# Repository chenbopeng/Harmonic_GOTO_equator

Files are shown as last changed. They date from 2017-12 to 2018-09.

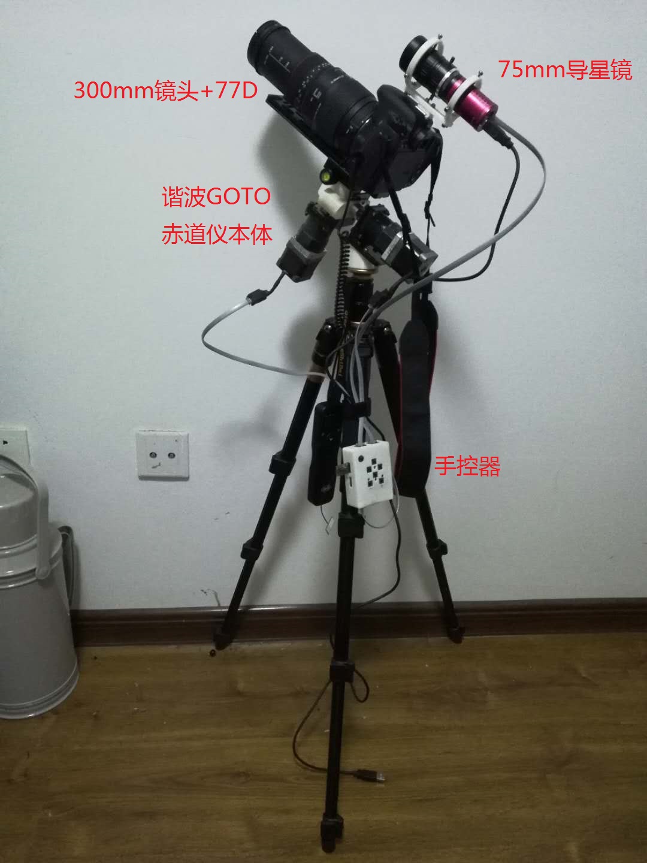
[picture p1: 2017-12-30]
doc/设备总体图.jpg

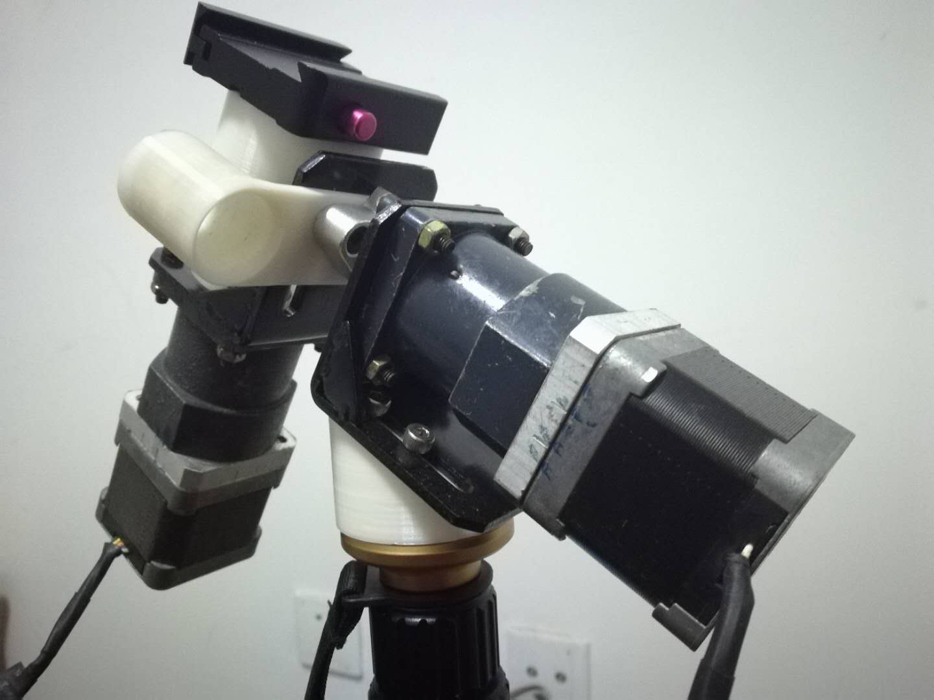
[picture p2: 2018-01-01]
doc/赤道仪本体实物图.jpg

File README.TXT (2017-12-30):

谐波GOTO赤道仪说明
重要声明：
本设计提供了一种谐波GOTO赤道仪的制作方法及全部原始技术资料。
本设计从共享之日起可供任何组织和个人免费获取，但禁止任何组织和个人在未经允许的条件下用于商业用途。
制作者需自行为其制作的实体所造成的一切后果负责，本设计作者不承担任何责任。
作者邮箱：c290129114@163.com

文件说明：
SRC文件夹为手控器源码及固件文件，开发及调试环境为Keil uVision5。
MACH文件夹为机械结构设计图文件，包括3D打印所需的STL文件等，设计软件为SOLIDWORKS 2015。
PCB文件夹为原理图与PCB设计图文件，设计软件为Altium Designer16。
DOC文件夹为文本及图片说明文件，包括安装及使用说明、装配示意图等。

如果您想快速制作一台属于自己的便携谐波GOTO赤道仪，可按照DOC文件夹下的说明文件按步骤制作即可！

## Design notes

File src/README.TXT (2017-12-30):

谐波GOTO控制手柄固件说明
硬件：
100减速比谐波电机（可通过修改EQ3D.H中的定义适配别的电机）
STM32C8T6最小系统
TMC2100步进电机驱动器（固定16细分，内差分至256细分）

版本实现：
双轴电跟,赤经轴跟踪精度无理论误差
按键控制及导星,速度2X,10X,100X,800X按键切换
南北半球、东西朝向按键切换
Stellarium及SkySafari5有线或WIFI无线GOTO控制

使用方法：
1.将赤道仪架设好并对准极轴，按键选择正确的半球和朝向
2.控制赤道仪使相机正对天空中（天赤道附近有助于提高精度）的任一亮星
3.stellarium或SkySafari5连接手柄，软件中找到该亮星并点击GOTO至此星
4.此时软件中望远镜的标记点会从南天极移动至该星，而赤道仪并不会动
5.此时已完成系统的初始化，可以开始GOTO至任意天体（注意!!!防止相机及镜头打腿!!!）

需改进：
中天翻转算法
回差控制

通信过程：
建立连接时
Stellarium发送 “#:GR#”     下位机回复 “00:00:01#”       //下位机回复当前赤经值
Stellarium发送 “#:GD#”     下位机回复 “+00:00:01#”      //下位机回复当前赤纬值

按CTRL1指向目标时
Stellarium发送“#:Q#:Sr 11:36:05#”    下位机回复“1”      //上位机发送目标赤经值，下位机回复1表示收到
Stellarium发送“:Sd -47?28:13#”       下位机回复“1”      //上位机发送目标赤纬值，下位机回复1表示收到
Stellarium发送“:MS#”                 下位机回复“0”      //上位机询问下位机是否能转到该位置，下位机回复0表示可以

skasafari5建立连接
“:GR#”
“:GD#”

“:Sr00:14:08#”
“:Sd+13*34:40#”
“:MS#”

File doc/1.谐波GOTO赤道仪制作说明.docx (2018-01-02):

# 谐波GOTO赤道仪制作说明

# 重要声明

本设计提供了一种谐波GOTO赤道仪的制作方法及全部原始技术资料。

本设计从共享之日起可供任何组织和个人免费获取，但禁止任何组织和个人在未经允许的条件下用于商业用途。

制作者需自行为其制作的实体所造成的一切后果负责，本设计作者不承担任何责任。

作者邮箱：c290129114@163.com

# 综述

## 制作谐波GOTO赤道仪的初衷

本人菜鸟天爱一枚，因为工作长期在各大城市出差，又经常手痒，EQ3D+小黑无法带在身边，因而萌生攒一套便携深空设备的想法，然而市面上已有的赤道仪系统的价格、便携性、易用性均让我不太满意，所以利用自己的专长，开始自己制作谐波GOTO赤道仪。

我的设计参考了论坛多位大神的设计经验，在此一并向他们表示感谢！

本赤道仪设计思路着重于便携、低成本和系统简洁，并在此基础上达到尽可能高的精度。可以看到几乎每一个零件和模块都是为这个指导思想服务。

## 本赤道仪目前实现功能

本赤道仪目前实现了：

1.双轴电跟（赤经轴跟踪精度无理论误差）

2.按键控制及导星控制

3. 2X,10X,100X,800X速度按键切换

4.南北半球、东西朝向按键切换

5.Stellarium及SkySafari5有线或WIFI无线GOTO控制

## 本赤道仪设计特色

1. 采用100:1减速比的谐波减速器，谐波减速器精度高，无回差。
2. 采用内差分至256细分的TMC2100高端步进电机驱动器，静音、无抖动、精度高。
3. 采用LX200串口通信协议，通过WIFI转串口模块，实现Stellarium及SkySafari5对赤道仪的无线控制，方便使用笔记本或手机在外场控制赤道仪。
4. 赤道仪本体重量1.8kg左右，背包即可轻松出行。

## 赤道仪测试效果展示

1.Stellarium无线控制。

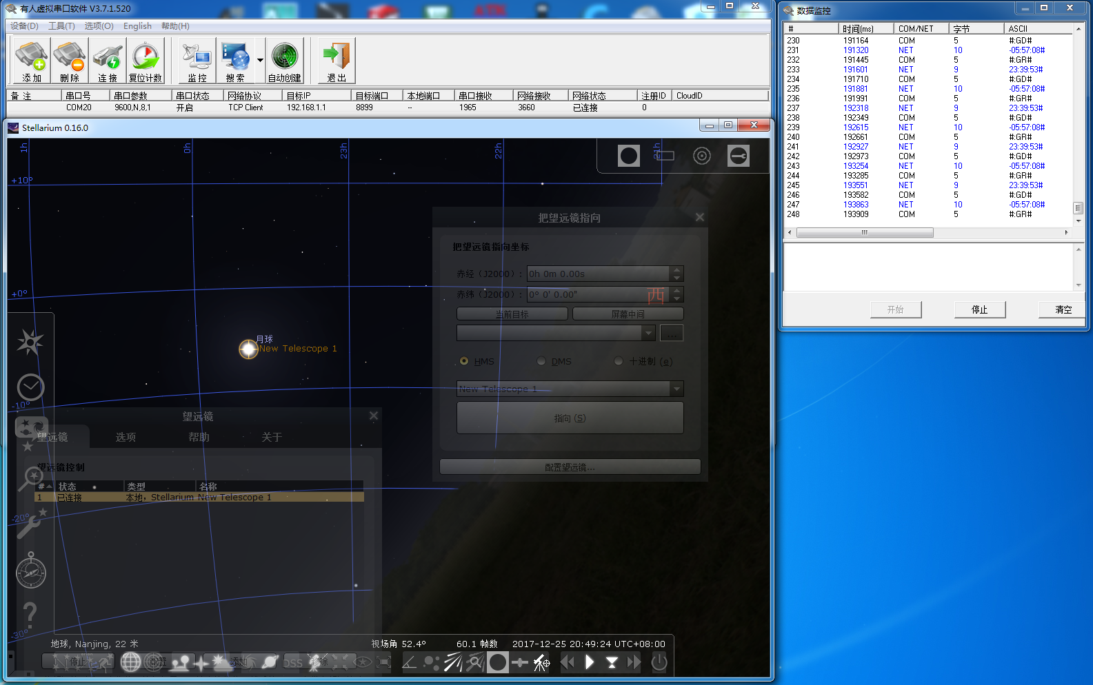
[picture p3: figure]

2. SkySafari5无线控制

3.导星曲线

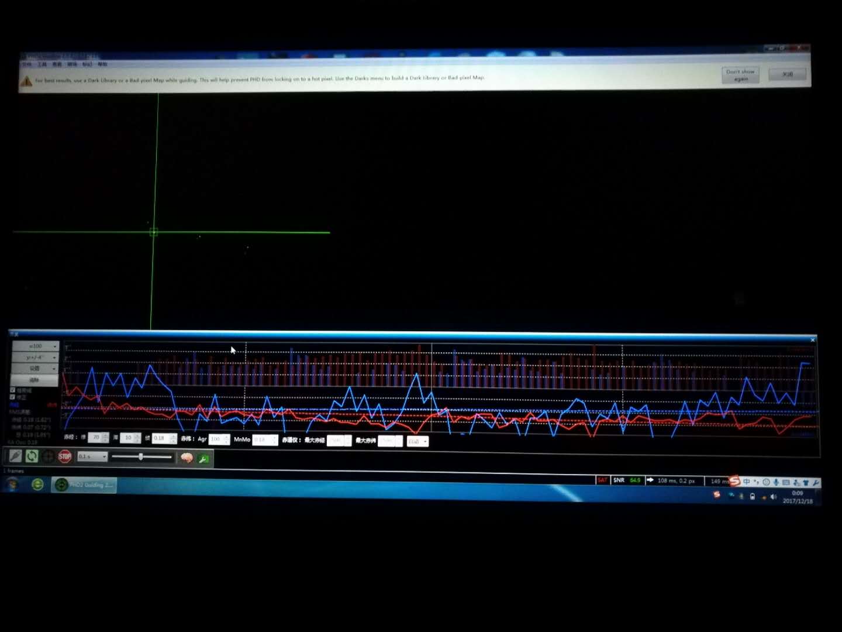
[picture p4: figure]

4.大角GOTO到M45（如图所示300mm镜头goto到位后还是需要微调，误差有可能是步进电机没有加减速控制而造成的丢步或超步导致的，也有可能是三脚架较差，微弱形变或抖动所造成）

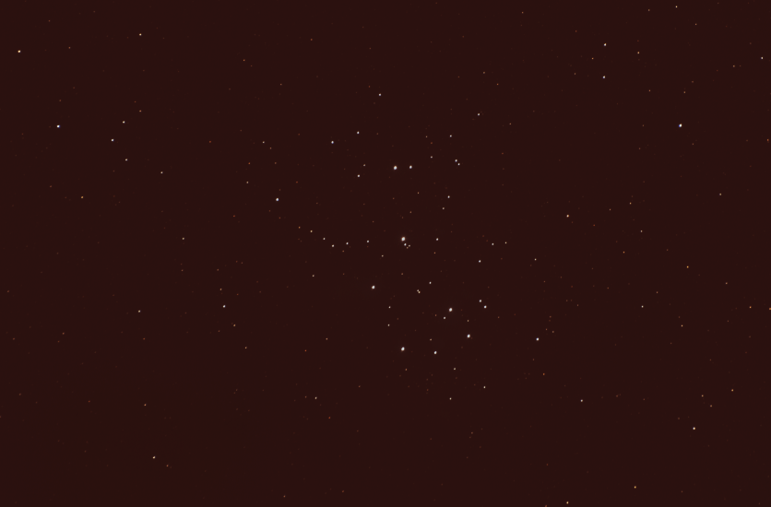
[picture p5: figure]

5.赤道仪整装图

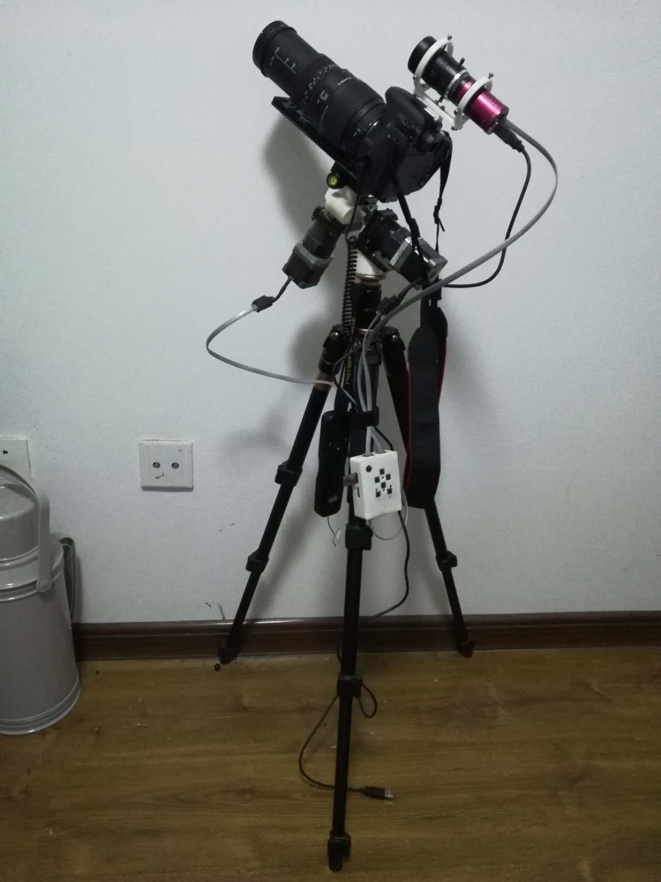
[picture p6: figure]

# 准备材料

接下来开始进入正题，如何制作一台自己的谐波GOTO赤道仪。

## 准备工具

电烙铁等焊接工具

万用表

内六扳手一套（尤其是M4）

十字起

热缩管或电工胶布

尖嘴钳

细导线若干

## 准备材料

详见《2.谐波GOTO赤道仪bom清单.xlsx》

## 调整电压

稳压模块在安装之前需要调整电压，以防电压过高烧毁后续电路。调压时，如下图左端供电（注意电源极性），右端用万用表电压档监测输出电压值，用小十字起旋转可调电位器，控制输出电压为5-5.5V左右即可。

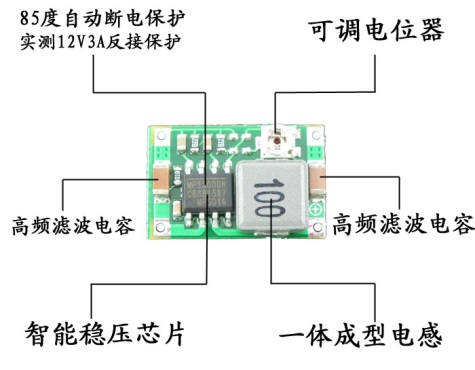
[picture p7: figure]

# 赤道仪本体制作

将材料如图安装即可。

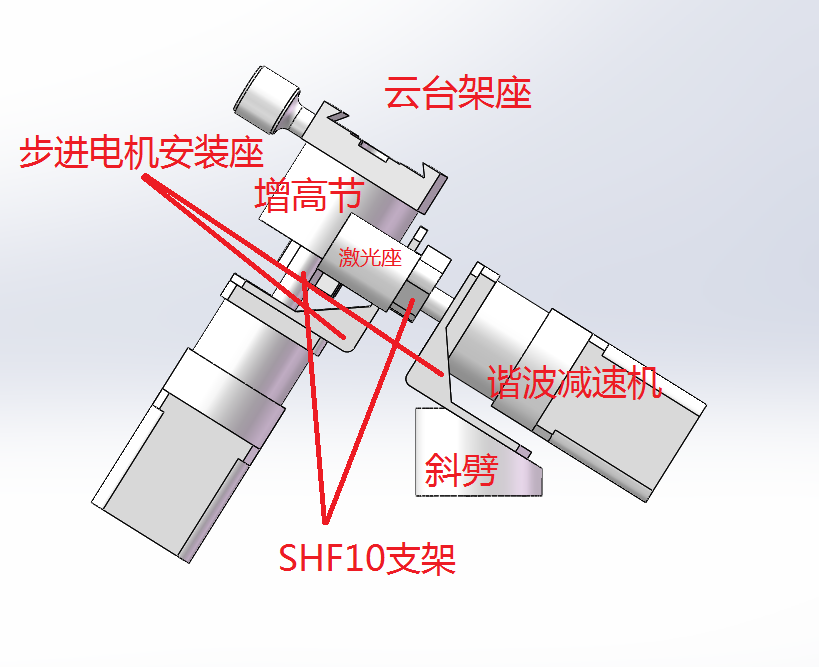
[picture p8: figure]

实物图


# 赤道仪手柄制作

## 手柄外观图

手柄由四部分组成，分别是主控板、按键板、wifi模块和外壳。

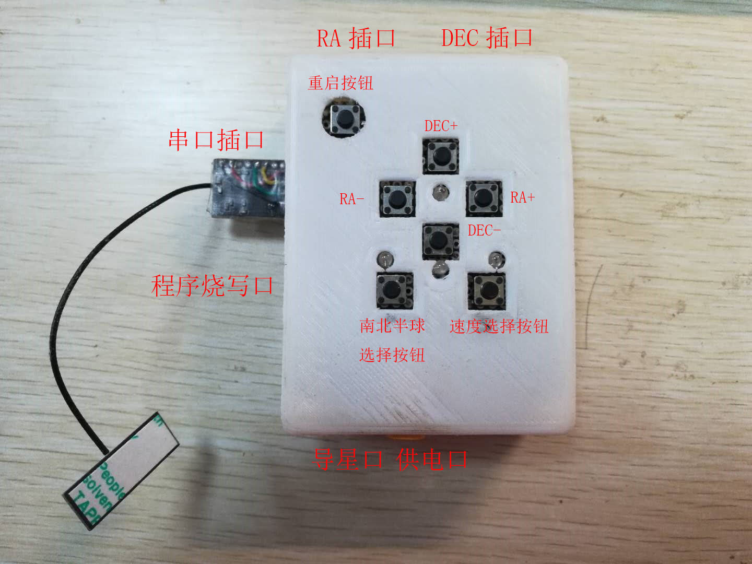
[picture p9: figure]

## 制作主控板

主控板布局如图

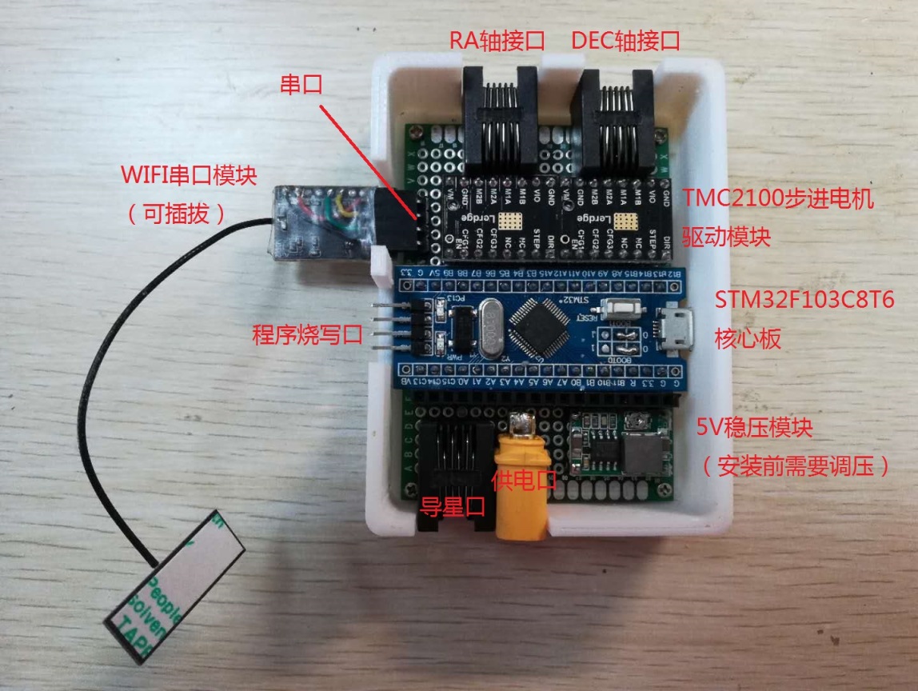
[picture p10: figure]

主控板背面焊线如图所示

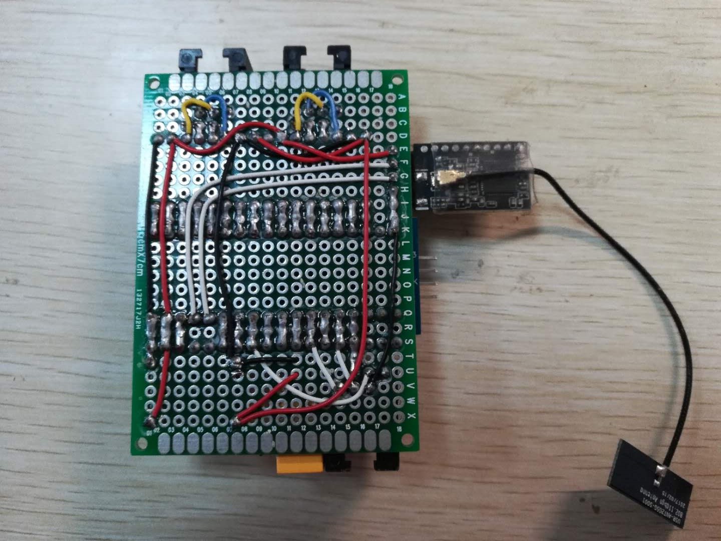
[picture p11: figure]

看不清焊线图也可以根据原理图进行焊线。

主控板原理图如下：

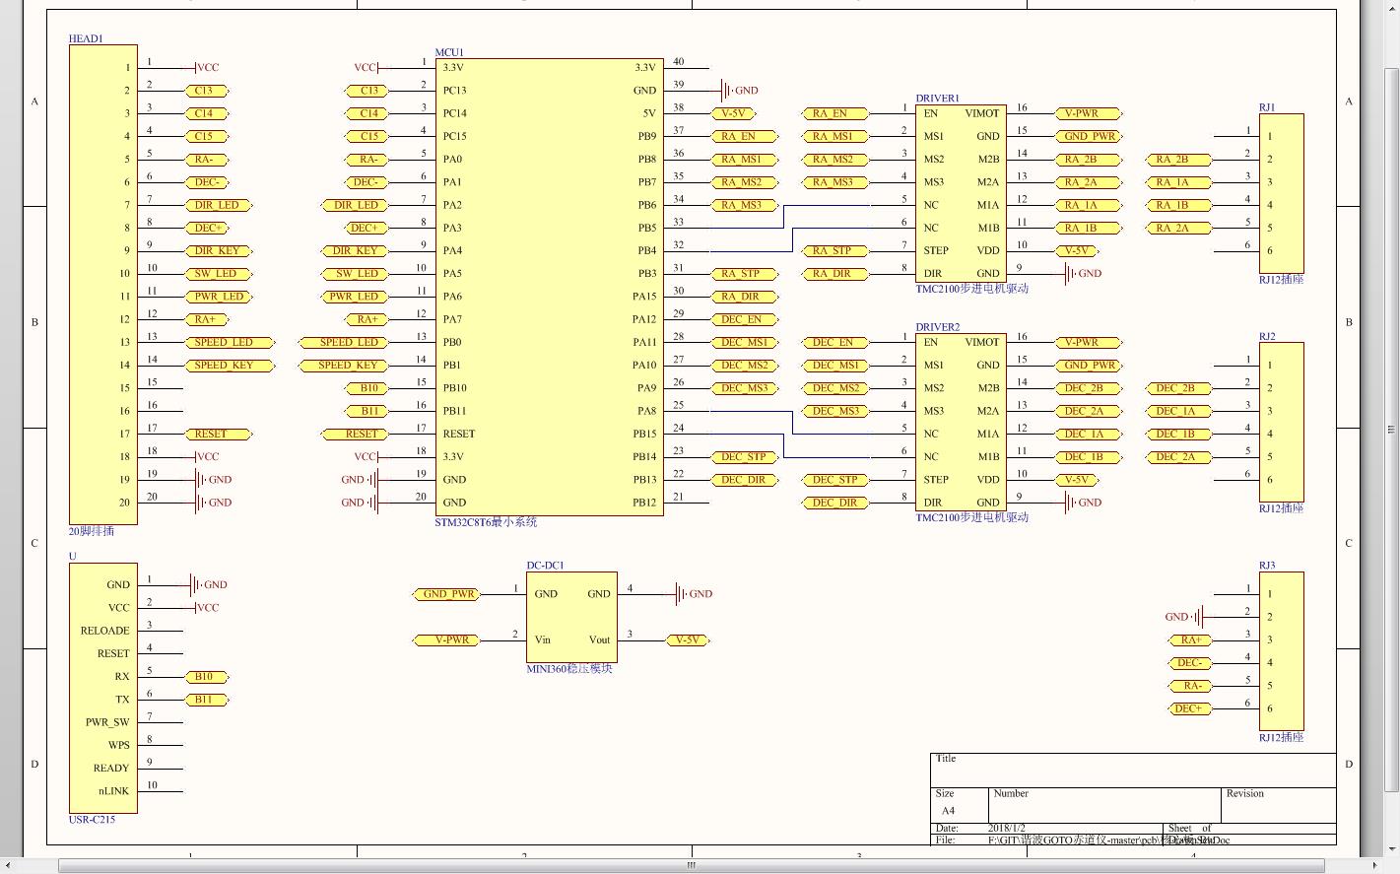
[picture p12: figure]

## 调整驱动器电流

主控板制作完成之后，首先需要对步进电机驱动器，即TMC2100模块进行电流调整之后才能连接步进电机，否则可能出现电机供电不足或者供电太大烧毁电机！

电流调整非常简单，先对主控板供电，然后在TMC2100驱动器上找到与下图红色表笔对应的小孔，该小孔内有一个可以用小一字起旋转的电位器，通过旋转该电位器并如图测量该点的电压，调整该点电压为0.26V即263mv即可（I=Vref*1.9，此时I=0.5A，这是经多次测试得到的较好的工作电流值）

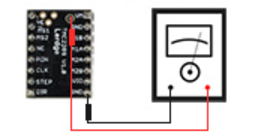
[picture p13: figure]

## 制作按键板

按键板正面布局（注意按钮的摆放方向）

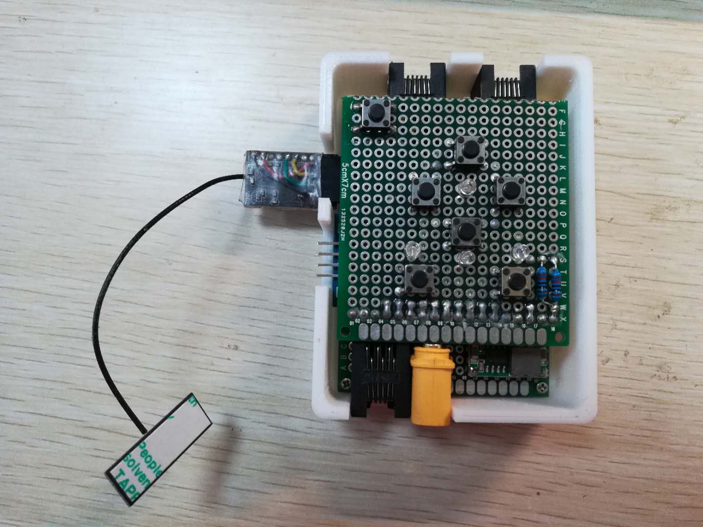
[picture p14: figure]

按键板背面焊接图

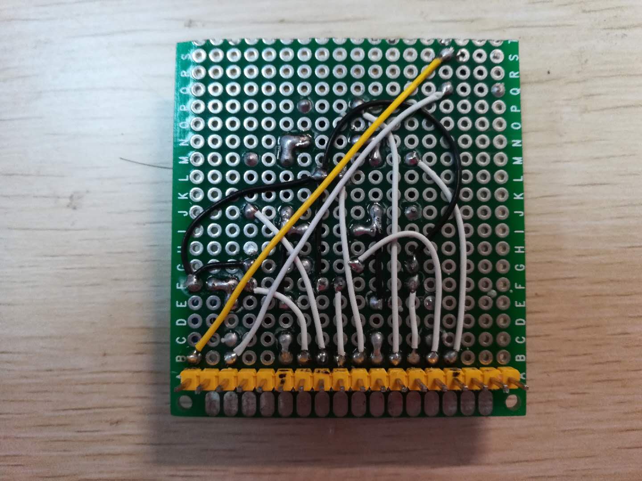
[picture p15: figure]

## 烧写固件

1. 安装j-link驱动，连接烧写器和电脑及赤道仪手柄。
2. 打开SEGGER>J-Link V4.90>J-flash软件。
3. 点击create a new project>star j-flash。
4. 点击options>project settings，如图进行设置。

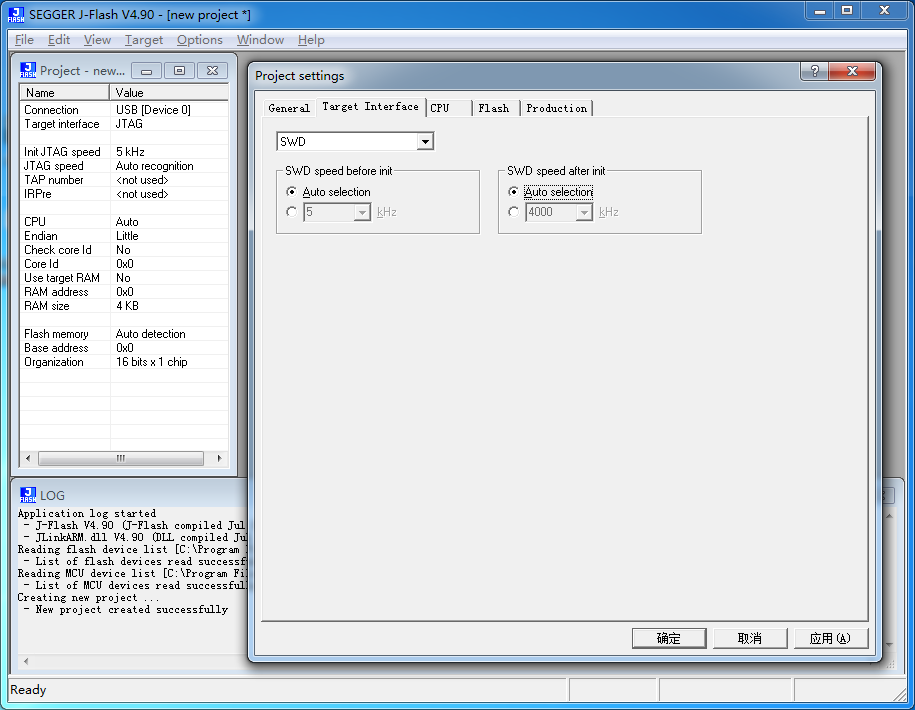
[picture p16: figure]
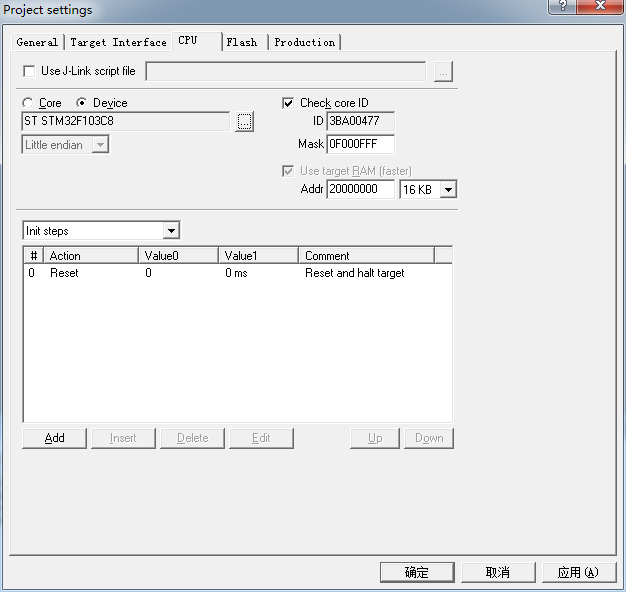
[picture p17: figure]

5. 点击file>open data file，如图选择.HEX固件文件。

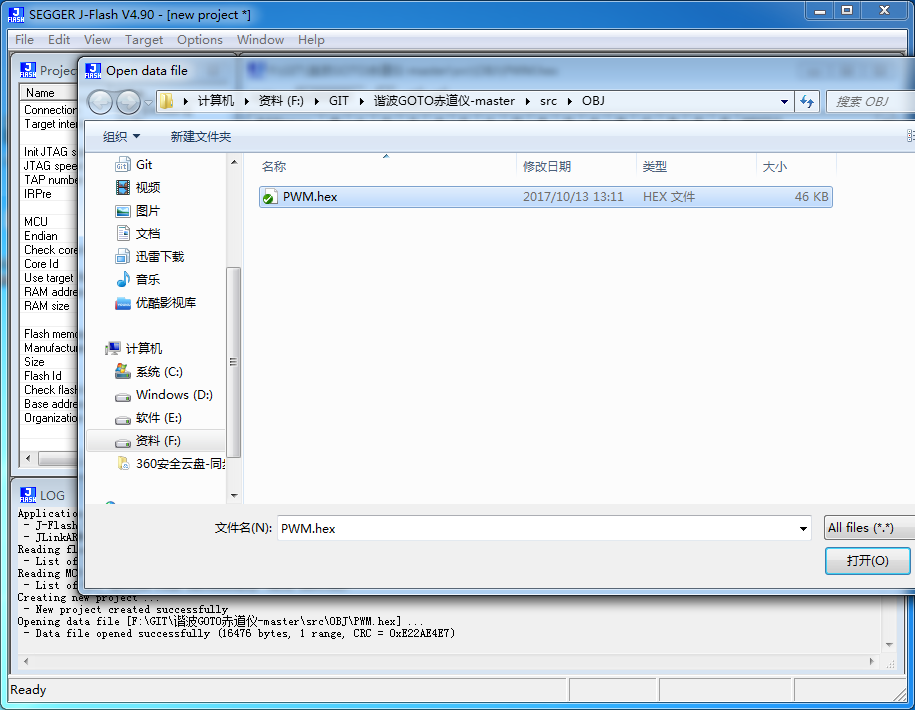
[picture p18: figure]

6. 按F7进行烧写。

# 软件设置

## wifi模块初始化设置

1. 连接usr_c215
2. 进入管理页面，IP地址为10.10.100.254，账号密码均为admin。

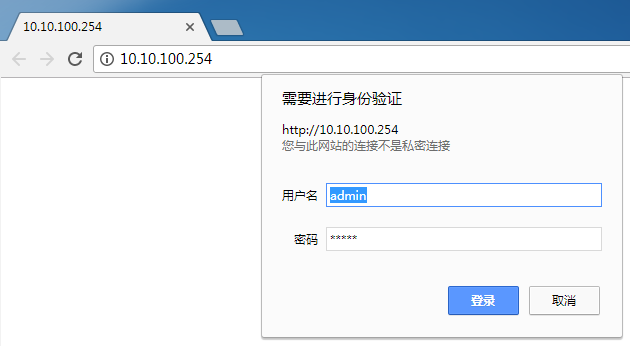
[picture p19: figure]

3. 如图设置WIFI参数并点击保存，但不要重启。

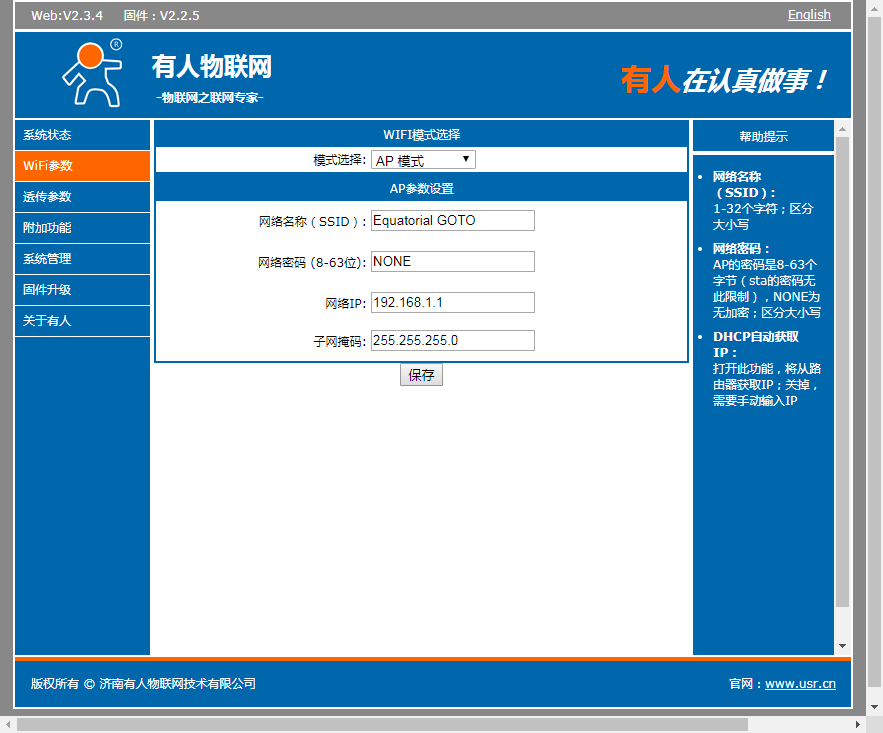
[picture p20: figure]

4. 如图设置串口参数，完成后点击保存并重启。

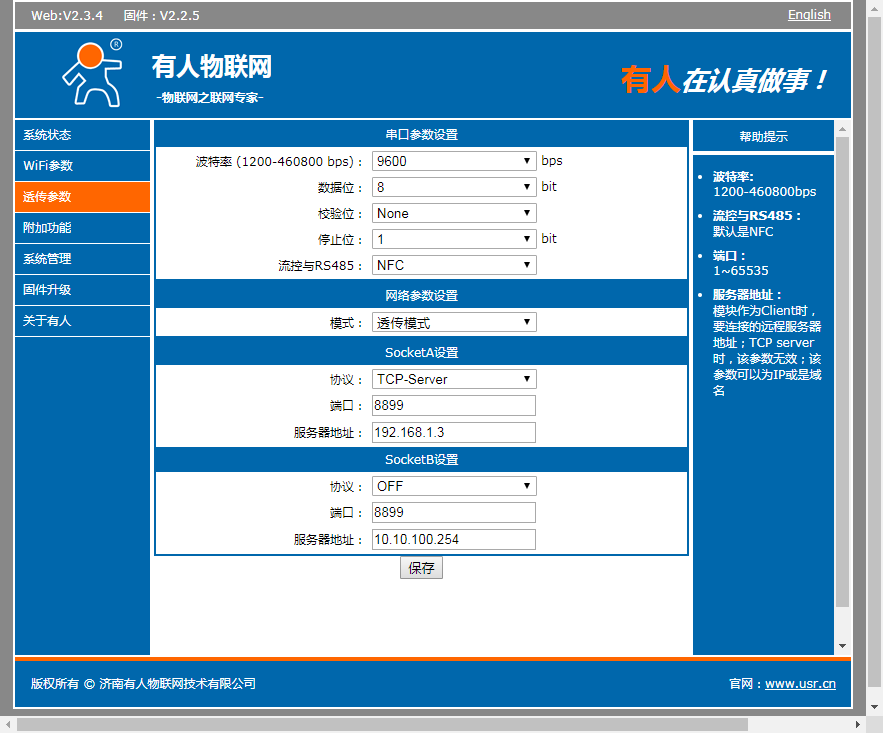
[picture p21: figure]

至此，WIFI模块已经设置完成！

## 电脑通过WIFI连接赤道仪

1. 下载安装WiFi虚拟串口软件http://www.usr.cn/Download/31.html
2. 打开软件，点击添加，如图设置生成一个虚拟串口

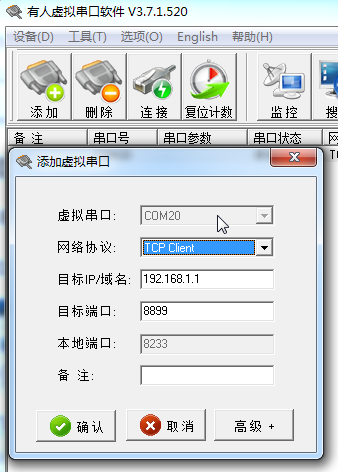
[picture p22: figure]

3. 打开Stellarium，点击设定>插件>望远镜控制，勾选启动时加载。然后重启Stellarium。

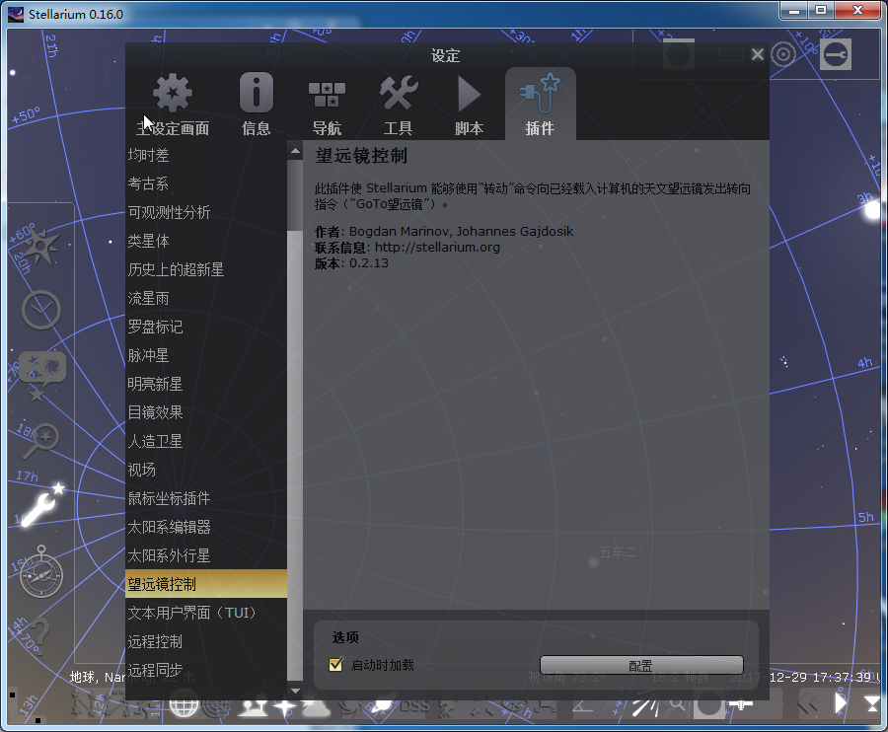
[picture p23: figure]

4. 点击新出现的赤道仪图标
5. 依次点击配置望远镜>添加，然后如图配置，点击确认后，选中生成的望远镜，点击启动即可。

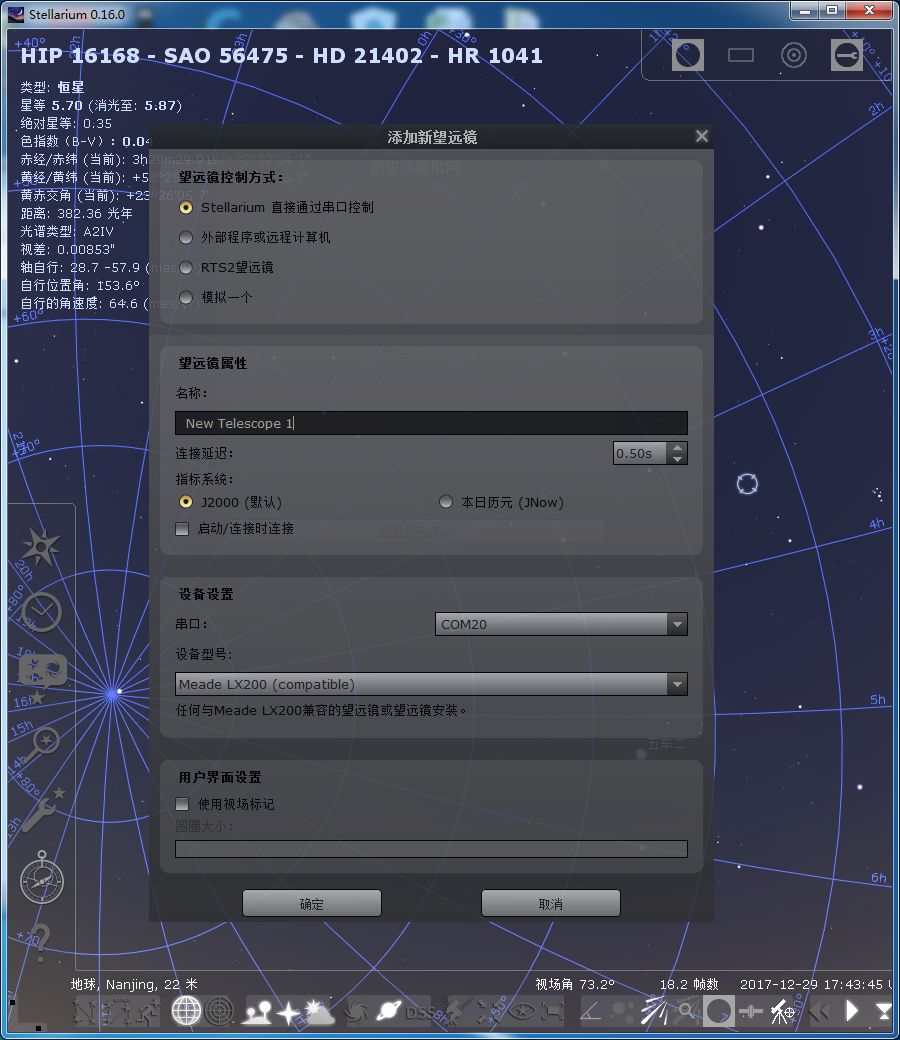
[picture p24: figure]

以后每次连接只需连接赤道仪的WIFI，打开Stellarium的赤道仪控制面板，选中赤道仪点击启动即可（Stellarium控制赤道仪GOTO到目标的快捷键为Ctrl+1（一号望远镜）

## 手机通过WiFi连接赤道仪

1. 下载安装SkySafari5。
2. 如图设置SkySafari5。

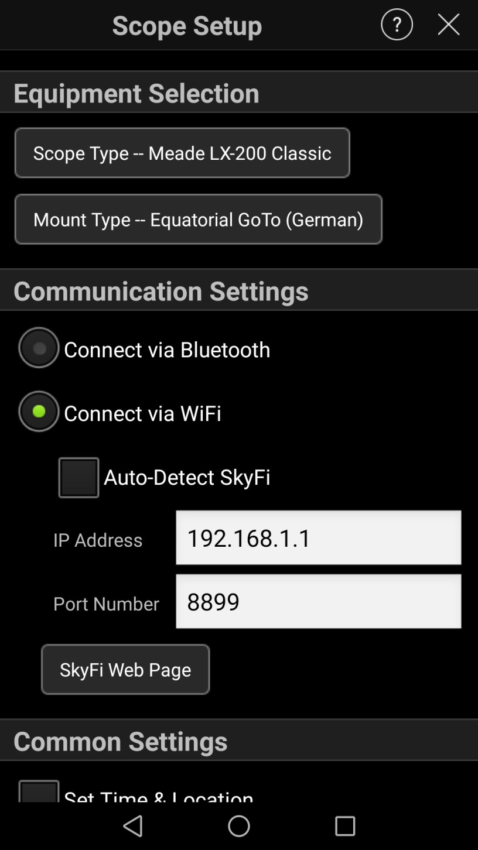
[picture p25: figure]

3. 手机连接赤道仪的WiFi热点。
4. 回到SkySafari5的主界面，切换到望远镜页面，点击connect即可。

以后只需重复3、4步骤即可。

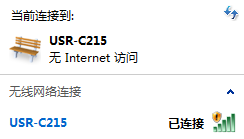
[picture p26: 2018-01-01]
doc/连接wifi.png

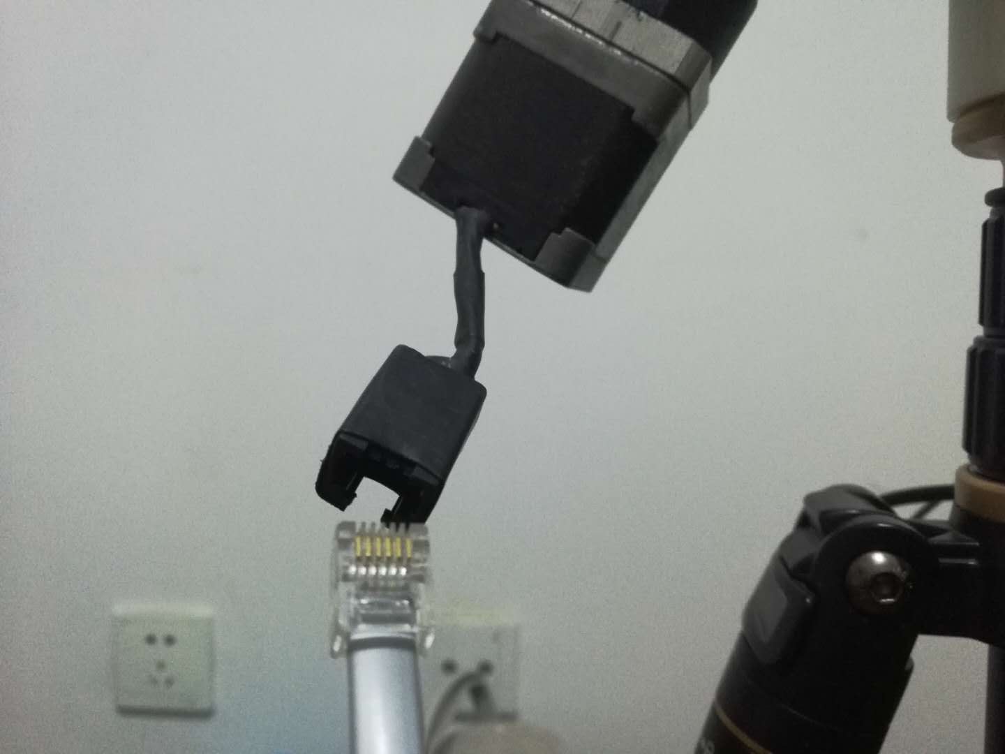
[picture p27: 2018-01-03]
doc/步进电机接口.jpg

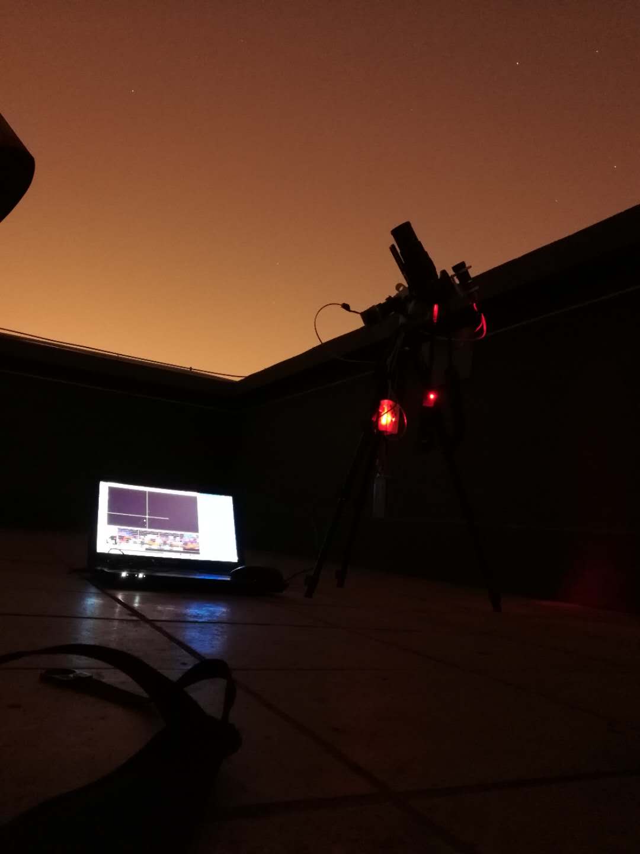
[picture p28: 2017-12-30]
doc/拍摄中.jpg

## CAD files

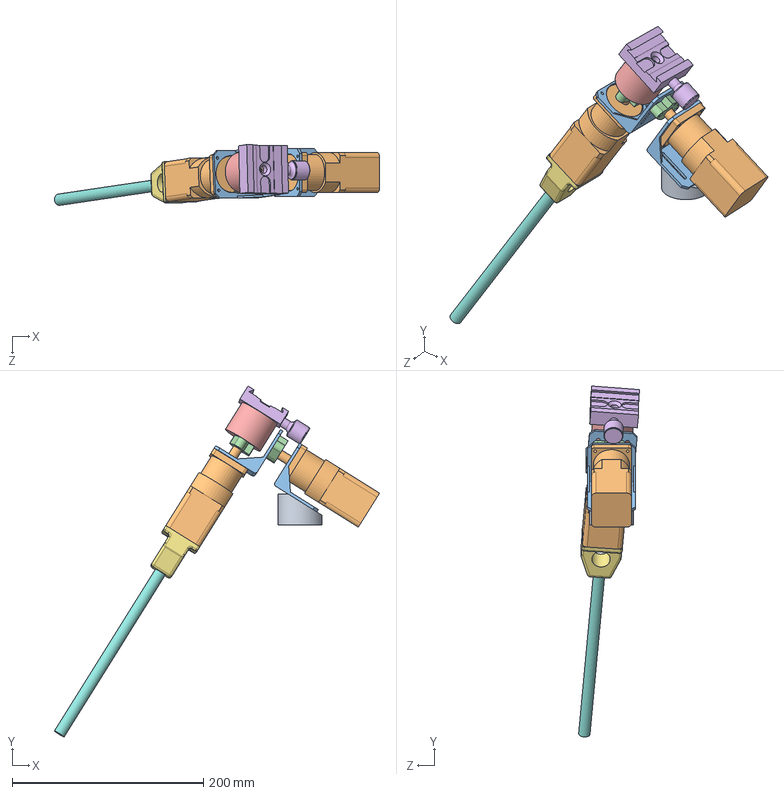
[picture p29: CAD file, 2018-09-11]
mach/谐波GOTO.SLDASM
340.0 x 367.0 x 63.6 mm
斜劈32度
100减速比谐波减速42步进电机 x 2
谐波减速电机安装座 x 2
SHF10光轴支架 x 2
增高节P50
K50云台板
重锤杆底座
重锤杆

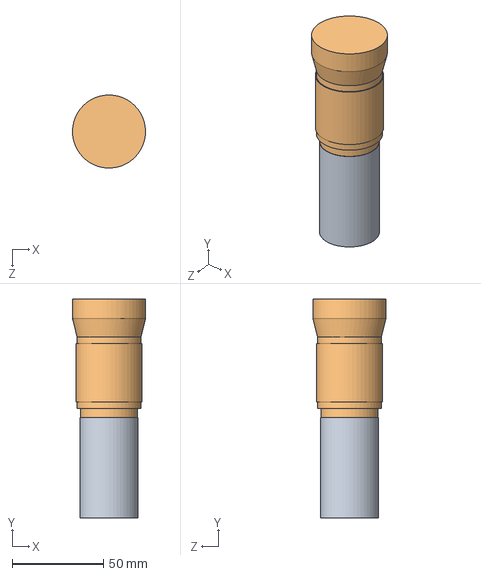
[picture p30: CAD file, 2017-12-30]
mach/热靴导星镜/工业镜头导星镜.SLDASM
40.0 x 119.9 x 40.0 mm
T7C摄像头
75mmf2.8工业镜头

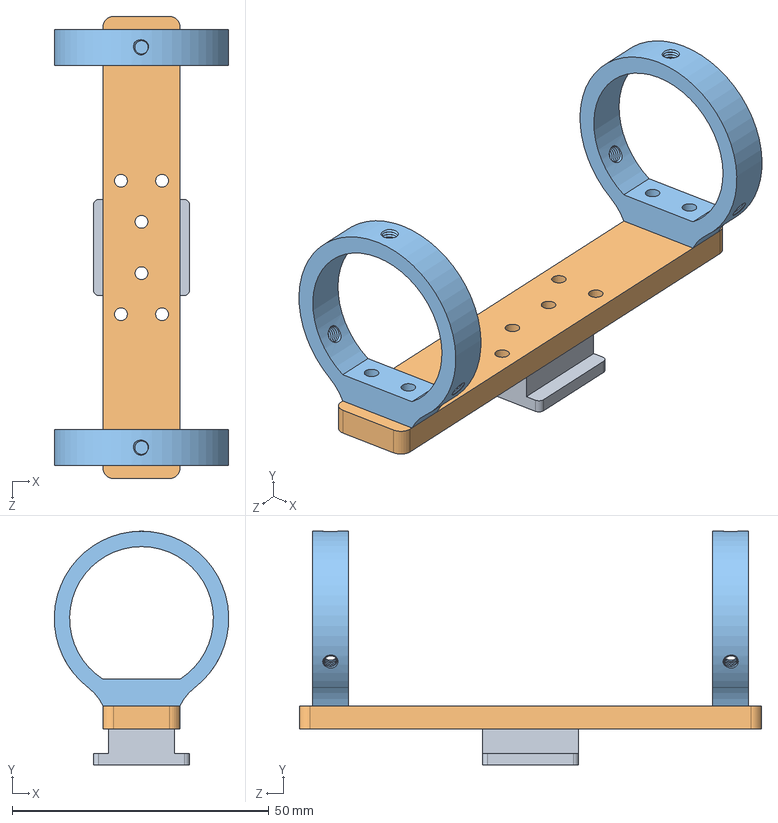
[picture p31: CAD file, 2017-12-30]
mach/热靴指星笔/热靴指星笔.SLDASM
34.0 x 45.5 x 90.0 mm
热靴底座
指星笔鸠尾板
指星笔抱箍 x 2

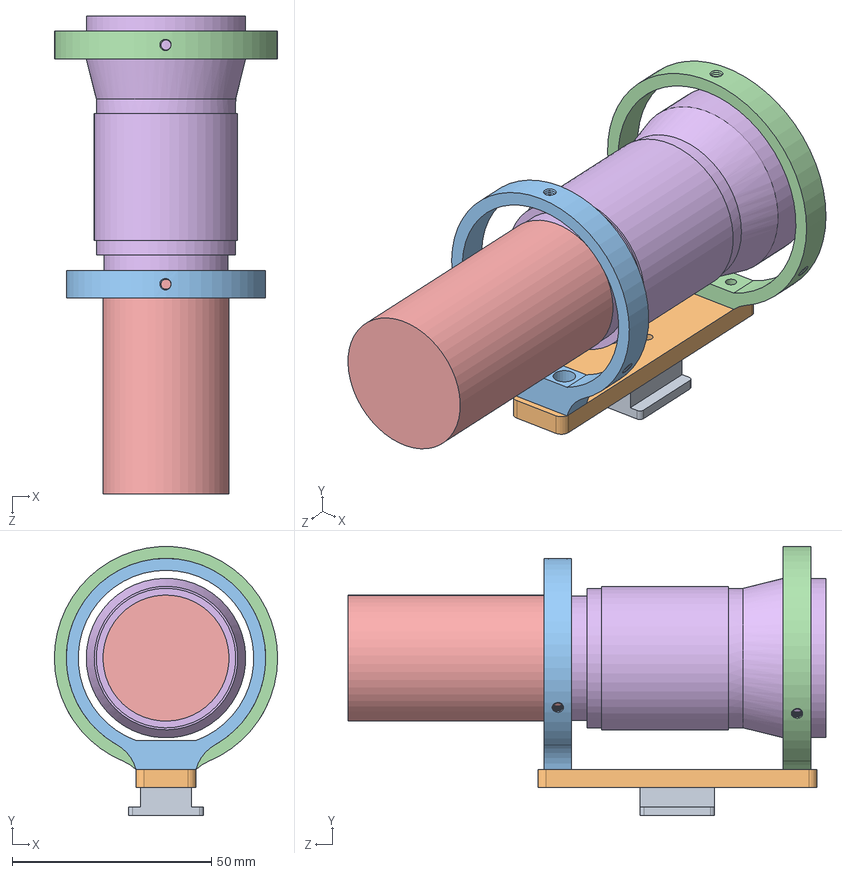
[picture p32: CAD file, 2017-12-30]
mach/热靴导星镜/热靴导星镜.SLDASM
56.0 x 67.5 x 119.9 mm
热靴底座
指星笔鸠尾板
T7C抱箍
mini导星镜抱箍
T7C摄像头
75mmf2.8工业镜头

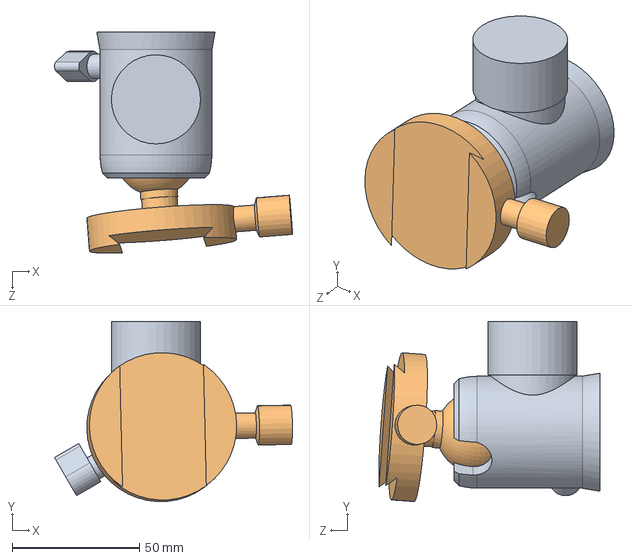
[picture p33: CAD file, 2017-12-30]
mach/球形云台.SLDASM
93.4 x 70.7 x 86.9 mm
球台底座
球台活动球

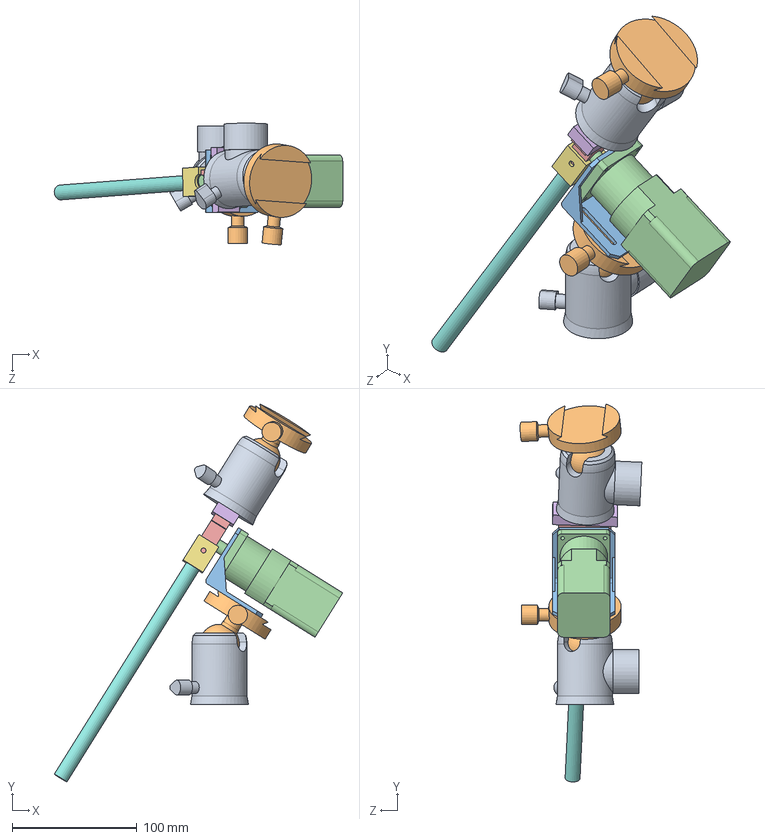
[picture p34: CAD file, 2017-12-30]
mach/单轴星野.SLDASM
231.2 x 302.8 x 97.5 mm
球台底座 x 2
球台活动球 x 2
谐波减速电机安装座
100减速比谐波减速42步进电机
SK10光轴支架
球台转接座
重锤连接件
重锤杆

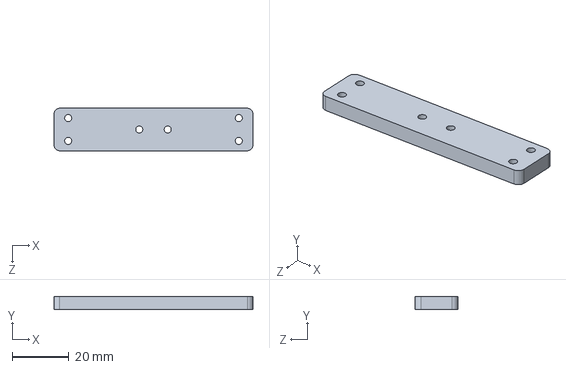
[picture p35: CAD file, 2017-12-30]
mach/热靴导星镜/指星笔鸠尾板.SLDPRT
70.0 x 4.50 x 15.0 mm

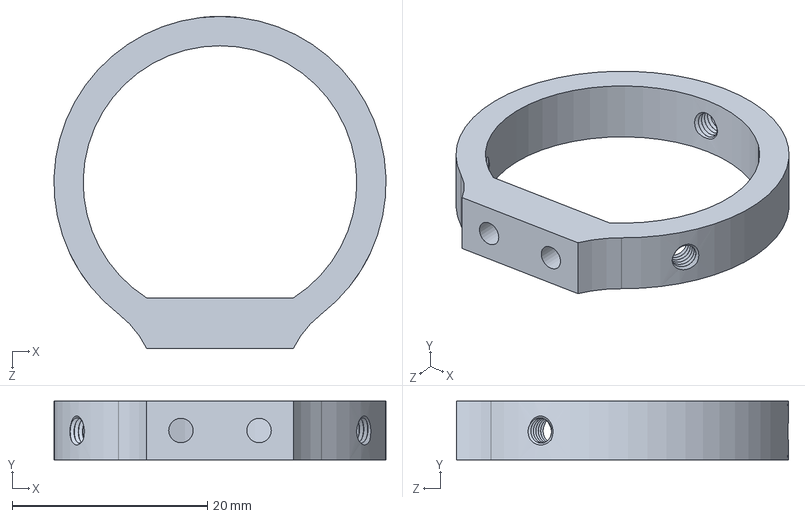
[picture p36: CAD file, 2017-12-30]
mach/热靴指星笔/指星笔抱箍.SLDPRT
34.0 x 6.00 x 34.0 mm

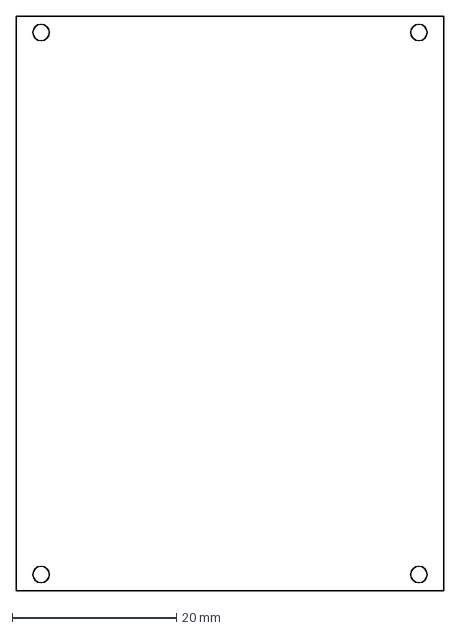
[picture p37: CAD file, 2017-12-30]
pcb/手控器驱动板.DXF
52.0 x 70.0 mm

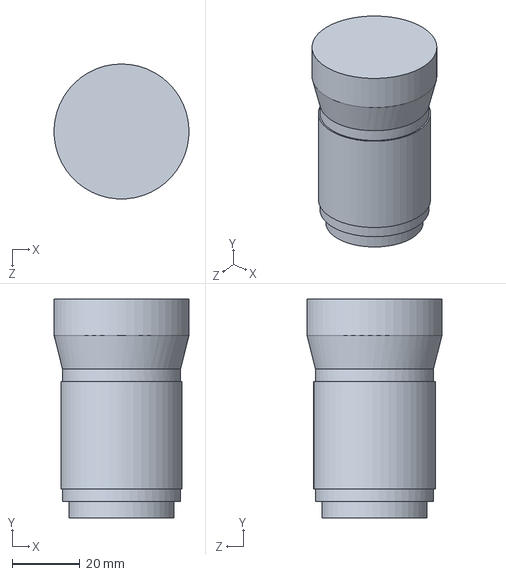
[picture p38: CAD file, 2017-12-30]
mach/热靴导星镜/75mmf2.8工业镜头.SLDPRT
40.0 x 64.9 x 40.0 mm

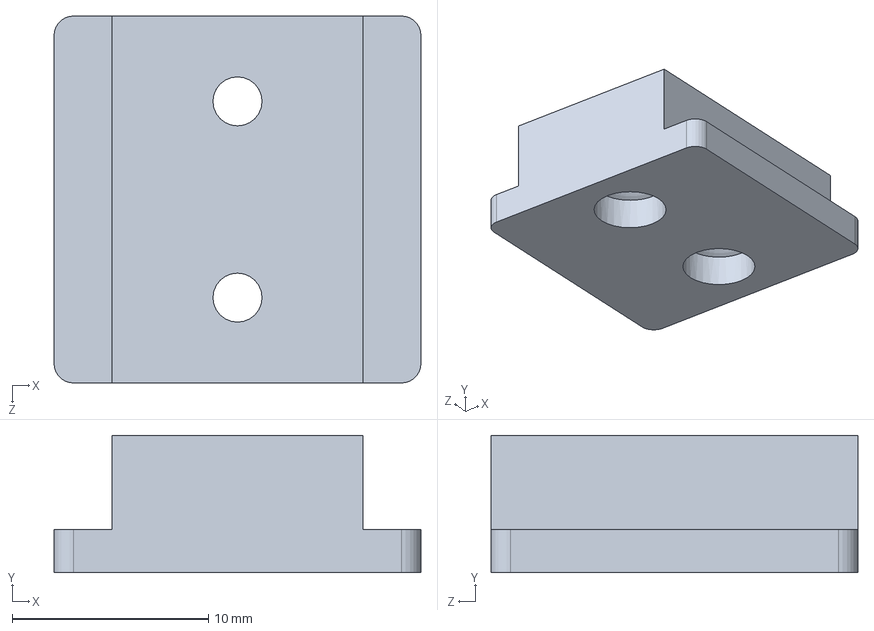
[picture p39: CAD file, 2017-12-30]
mach/热靴指星笔/热靴底座.SLDPRT
18.7 x 7.00 x 18.7 mm

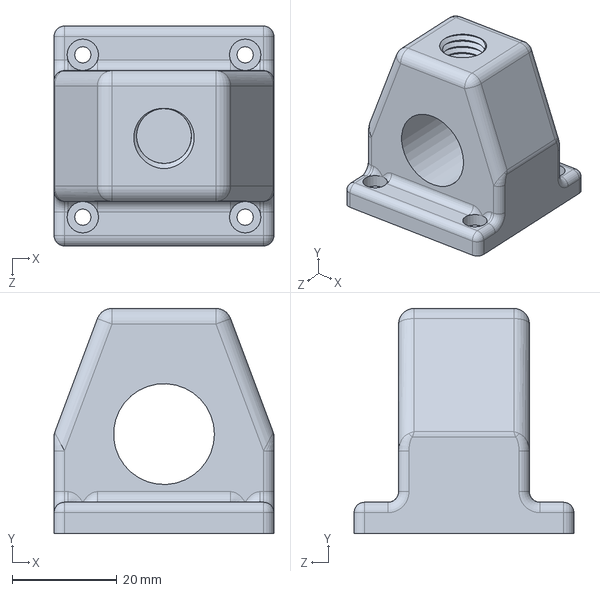
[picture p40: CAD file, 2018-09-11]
mach/重锤杆底座.SLDPRT
42.0 x 43.0 x 42.0 mm

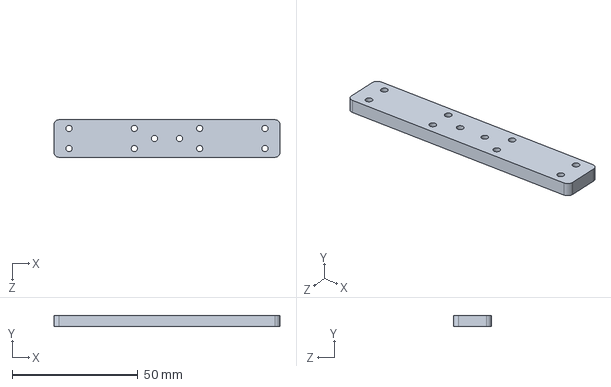
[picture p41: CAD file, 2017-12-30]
mach/热靴指星笔/指星笔鸠尾板.SLDPRT
90.0 x 4.50 x 15.0 mm

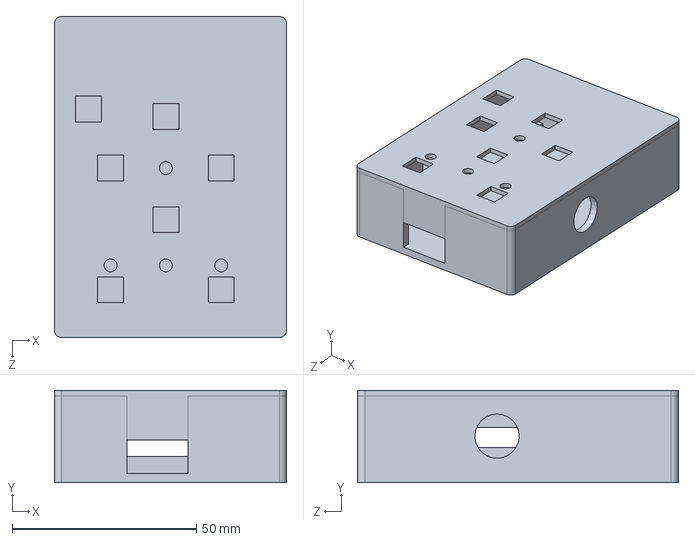
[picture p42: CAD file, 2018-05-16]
mach/第四版外壳.SLDPRT
63.0 x 25.0 x 87.0 mm

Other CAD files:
mach/热靴导星镜/T7C摄像头.SLDPRT
mach/第四版外壳盖.sldprt
mach/SK10光轴支架.SLDPRT
mach/热靴导星镜/mini导星镜抱箍.SLDPRT
mach/100减速比谐波减速42步进电机.SLDPRT
mach/K50云台板.SLDPRT
mach/SHF10光轴支架.SLDPRT
mach/增高节P50.SLDPRT
mach/斜劈20度.SLDPRT
mach/斜劈22度.SLDPRT
mach/斜劈32度.SLDPRT
mach/激光安装座.SLDPRT
mach/热靴导星镜/T7C抱箍.SLDPRT
mach/热靴导星镜/热靴底座.SLDPRT
mach/球台底座.SLDPRT
mach/球台活动球.SLDPRT
mach/球台转接座.SLDPRT
mach/球台转接座3D打印.SLDPRT
mach/第三版外壳底.SLDPRT
mach/第三版外壳盖.SLDPRT
mach/第四版外壳底.sldprt
mach/谐波减速电机安装座.SLDPRT
mach/重锤杆.SLDPRT
mach/重锤连接件.SLDPRT

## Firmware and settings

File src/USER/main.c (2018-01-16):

#include "delay.h"
#include "sys.h"
#include "dma.h"
#include "timer.h"
#include "EQ3D.h"
#include "usart.h"
#include "command.h"

u8 data_receive_buffer[USART_REC_LEN];  //来自于串口DMA输入
u8 step_flag=0;  //定时器中断标志

int main(void)
{
    s32 current_pos[2]= {0,0}, target_pos[2]= {0,0};
    s32 target_ra=0, target_dec=0;
    int ra_step=0, dec_step=0;
    u8 decode_state=0, dir_state[2]= {0,0} ;
    u16 move_speed=1;
    s8 remote_key_state[2]= {0,0}, local_key_state[2]= {0,0}, key_state[2]= {0,0} ;
		u16 shutter[2]={0,0}, timer_counter=0 , sec_counter=0 ;

    delay_init();	       //延时函数初始化
    NVIC_PriorityGroupConfig(NVIC_PriorityGroup_2);// 设置中断优先级分组2
    uart3_init(9600);
    DMA_TX_init((u32)data_receive_buffer, USART_REC_LEN);
    DMA_RX_init((u32)data_receive_buffer, USART_REC_LEN);
    EQ3D_GPIO_KEY_Config();
    EQ3D_GPIO_OUT_Config();
    TIM3_Int_Init(STP_INTERVAL, 35); //42步进电机3595+1微秒/拍，
    PWR_LED = 1; //电源指示灯

    while(1)
    {
        if(data_receive_buffer[USART_REC_LEN - 1] == 1)  //DMA收到消息标志
        {
            data_receive_buffer[USART_REC_LEN - 1] = 0; //清理标志
					
						SHUTTER_CONTROL( data_receive_buffer, shutter); //相机快门线控制
					
            decode_state = LX200( data_receive_buffer, current_pos, target_pos ); //LX200协议解析
            REMOTE_KEY_CONTROL(remote_key_state,decode_state); //无线按键控制解码
            if(GOTO_CHECK(decode_state) == 0xff) //目标位置齐备
            {
                if(current_pos[0] == 0 && current_pos[1] == 0) //如果是系统刚开始运行，则将第一次的GOTO信息设置为当前位置
                {
                    current_pos[0] = target_pos[0];
                    current_pos[1] = target_pos[1];
                }
                else  //正常GOTO时，根据目标位置计算步数及方向，根据步数和方向乘以系数得到实际需要的步数和方向
                {
                    target_ra = target_pos[0];
                    target_dec = target_pos[1];
                    ra_step	=	RA_STEP_CALCULATE(current_pos[0], target_pos[0], RA_STP_ANGLE );   //计算各轴所需步数和方向，正负号代表方向
                    dec_step	=	DEC_STEP_CALCULATE(current_pos[1], target_pos[1], DEC_STP_ANGLE );

                    if(ra_step>0)
                    {
                        ra_step=ra_step*((float) NORM_STP_COUNT/(float)(NORM_STP_COUNT+GOTO_STP_COUNT));
                    }
                    else
                    {
                        ra_step=ra_step*((float) NORM_STP_COUNT/(float)(NORM_STP_COUNT-GOTO_STP_COUNT));
                    }
                }
            }
        }
        if(step_flag == 1)  //步进标志
        {
            step_flag = 0;  //清除标志
            DIR_CONTROL(dir_state);  //按键切换赤道仪移动方向基准值（北半球东向，北半球西向，南半球东向，南半球西向）是为了解决中天翻转和南北半球设置的问题
            if(ra_step == 0 && dec_step == 0)  //无需GOTO
            {
                LOCAL_KEY_CONTROL(local_key_state); //手柄控制赤道仪移动
                KEY_CONTROL_MIX(remote_key_state,local_key_state,key_state);  //手柄与遥控按键数据融合
                move_speed=SPEED_CONTROL();  //按键时赤道仪移动速度设置
                HANDLE_CONTROL( move_speed,dir_state,key_state);  //响应按键或正常速度跟踪
            }
            else  //需要GOTO
            {
                GOTO( &ra_step, &dec_step,dir_state);    //执行GOTO任务
                current_pos[0] = CURRENT_POS_RA ( target_ra, ra_step, RA_STP_ANGLE );   //更新当前指向
                current_pos[1] = CURRENT_POS_DEC ( target_dec, dec_step, DEC_STP_ANGLE );
            }
						timer_counter++;
        }
				
				if(shutter[1]!=0&&timer_counter>=30769)//快门控制
				{
					timer_counter=0;
					sec_counter++;
					if(sec_counter==5&&shutter[0]!=0) //延时5秒后，B门拍照
					{
						PCout(13)=0;
						PBout(12)=0;
					}
					if(sec_counter>=(shutter[0]+5))  //到时停止B门
					{
						PCout(13)=1;
						PBout(12)=1;
						shutter[1]--;
						sec_counter=0;
					}
				}
    }
}

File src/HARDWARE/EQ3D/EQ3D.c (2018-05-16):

#include "EQ3D.h"

void EQ3D_GPIO_OUT_Config(void)
{
    GPIO_InitTypeDef GPIO_InitStructure;
    RCC_APB2PeriphClockCmd(RCC_APB2Periph_GPIOA | RCC_APB2Periph_GPIOB | RCC_APB2Periph_GPIOC, ENABLE);

    RCC_APB2PeriphClockCmd(RCC_APB2Periph_AFIO, ENABLE);
    GPIO_PinRemapConfig(GPIO_Remap_SWJ_JTAGDisable, ENABLE);

    GPIO_InitStructure.GPIO_Pin = GPIO_Pin_2 | GPIO_Pin_5 | GPIO_Pin_6 | GPIO_Pin_8 | GPIO_Pin_9 | GPIO_Pin_10 | GPIO_Pin_11 | GPIO_Pin_12 | GPIO_Pin_15;
    GPIO_InitStructure.GPIO_Speed = GPIO_Speed_50MHz;
    GPIO_InitStructure.GPIO_Mode = GPIO_Mode_Out_PP;
    GPIO_Init(GPIOA, &GPIO_InitStructure);

    GPIO_InitStructure.GPIO_Pin = GPIO_Pin_0 | GPIO_Pin_3 | GPIO_Pin_4 | GPIO_Pin_5 | GPIO_Pin_6 | GPIO_Pin_7 | GPIO_Pin_8 | GPIO_Pin_9 | GPIO_Pin_12 | GPIO_Pin_13 | GPIO_Pin_14 | GPIO_Pin_15;
    GPIO_InitStructure.GPIO_Speed = GPIO_Speed_50MHz;
    GPIO_InitStructure.GPIO_Mode = GPIO_Mode_Out_PP;
    GPIO_Init(GPIOB, &GPIO_InitStructure);

    GPIO_InitStructure.GPIO_Pin = GPIO_Pin_13 ;
    GPIO_InitStructure.GPIO_Speed = GPIO_Speed_50MHz;
    GPIO_InitStructure.GPIO_Mode = GPIO_Mode_Out_PP;
    GPIO_Init(GPIOC, &GPIO_InitStructure);

    PCout(13)=1;  //相机快门指示灯
    PBout(12)=1;  //相机快门控制引脚
    RA_EN = STEPPER_MOTOR_STAR;
    DEC_EN = STEPPER_MOTOR_STAR;
}

void EQ3D_GPIO_KEY_Config(void)
{
    GPIO_InitTypeDef GPIO_InitStructure;
    RCC_APB2PeriphClockCmd(RCC_APB2Periph_GPIOA | RCC_APB2Periph_GPIOB, ENABLE);//使能PORTA,PORTC时钟

    GPIO_PinRemapConfig(GPIO_Remap_SWJ_JTAGDisable, ENABLE);//关闭jtag，使能SWD，可以用SWD模式调试

    GPIO_InitStructure.GPIO_Pin  = GPIO_Pin_0 | GPIO_Pin_1 | GPIO_Pin_3 | GPIO_Pin_4 | GPIO_Pin_7;
    GPIO_InitStructure.GPIO_Mode = GPIO_Mode_IPU; //设置成上拉输入
    GPIO_Init(GPIOA, &GPIO_InitStructure);

    GPIO_InitStructure.GPIO_Pin  = GPIO_Pin_1;
    GPIO_InitStructure.GPIO_Mode = GPIO_Mode_IPU; //设置成上拉输入
    GPIO_Init(GPIOB, &GPIO_InitStructure);//初始化
}
void DEC_STEP_Config(u8 a)
{
    switch (a)
    {
    case 1:
        DEC_MS0 = 0; //1MS0 //DEC
        DEC_MS1 = 0; //1MS1
        DEC_MS2 = 0; //1MS2
        break;
    case 2:
        DEC_MS0 = 1; //1MS0
        DEC_MS1 = 0; //1MS1
        DEC_MS2 = 0; //1MS2
        break;
    case 4:
        DEC_MS0 = 0; //1MS0
        DEC_MS1 = 1; //1MS1
        DEC_MS2 = 0; //1MS2
        break;
    case 8:
        DEC_MS0 = 1; //1MS0
        DEC_MS1 = 1; //1MS1
        DEC_MS2 = 0; //1MS2
        break;
    case 16:
        DEC_MS0 = 0; //1MS0
        DEC_MS1 = 0; //1MS1
        DEC_MS2 = 1; //1MS2
        break;
    default:
        DEC_MS0 = 1; //1MS0
        DEC_MS1 = 1; //1MS1
        DEC_MS2 = 1; //1MS2
    }
}

void RA_STEP_Config(u8 a)
{
    switch (a)
    {
    case 1:
        RA_MS0 = 0; //1MS0  //RA
        RA_MS1 = 0; //1MS1
        RA_MS2 = 0; //1MS2
        break;
    case 2:
        RA_MS0 = 1; //1MS0
        RA_MS1 = 0; //1MS1
        RA_MS2 = 0; //1MS2
        break;
    case 4:
        RA_MS0 = 0; //1MS0
        RA_MS1 = 1; //1MS1
        RA_MS2 = 0; //1MS2
        break;
    case 8:
        RA_MS0 = 1; //1MS0
        RA_MS1 = 1; //1MS1
        RA_MS2 = 0; //1MS2
        break;
    case 16:
        RA_MS0 = 0; //1MS0
        RA_MS1 = 0; //1MS1
        RA_MS2 = 1; //1MS2
        break;
    default:
        RA_MS0 = 1; //1MS0
        RA_MS1 = 1; //1MS1
        RA_MS2 = 1; //1MS2
    }
}


void EQ3D_STEP(u8 stp_ra, u8 stp_dec)  //向步进电机驱动器按需发送脉冲
{
    u8 a;
    RA_STP = stp_ra;
    DEC_STP = stp_dec;
    for(a = 22; a > 0; a--) {};
    RA_STP = 0;
    DEC_STP = 0;
}

void HANDLE_CONTROL(u16 speed, u8 *dir_state, s8 *key_statue) //按指定的速度、基准方向、方向执行手控器按键的动作，以及正常速度跟踪
{
    u16 temp;
    static u16 ra_stp_count = 1, dec_stp_count = 1;
    u32 ra_overflows, dec_overflows;
    u8 ra_stp_flag = 0, dec_stp_flag = 0;

    ra_stp_count++;
    dec_stp_count++;

    if(key_statue[0]==0&&key_statue[1]==0)
    {
        SW_LED=0;   //按键指示灯
    }
    else
    {
        SW_LED=1;
    }

    switch (key_statue[0])//RA运动计算
    {
    case 0:  //RA正常跟踪
        RA_DIR = !dir_state[0];
        ra_overflows = NORM_STP_COUNT;
        break;
    case -1:  //RA+  S+1倍速
        RA_DIR = !dir_state[0];
        ra_overflows = NORM_STP_COUNT/(speed+1);
        break;
    case 1:  //RA-  S-1倍速
        RA_DIR = dir_state[0];
        temp=speed-1;
        if(temp==0)
        {
            ra_overflows=0xfffff;   //当2倍速时，使得计数无法达到溢出值，以此使RA轴停转
        }
        else
        {
            ra_overflows = NORM_STP_COUNT/(speed-1);
        }
        break;
    default:
        break;
    }
    switch (key_statue[1])//DEC运动计算
    {
    case 0:  //DEC停转
        dec_overflows = NORM_STP_COUNT;
        dec_stp_count=0;	//不加这句则无法正常起转，原因待查
        break;
    case 1:  //DEC+
        DEC_DIR = dir_state[1];
        dec_overflows = NORM_STP_COUNT/speed;
        break;
    case -1:  //DEC-
        DEC_DIR = !dir_state[1];
        dec_overflows = NORM_STP_COUNT/speed;
        break;
    default:
        break;
    }
    if(ra_stp_count > ra_overflows)
    {
        ra_stp_count = 1;
        ra_stp_flag = 1;
    }
    else
    {
        ra_stp_flag = 0;
    }
    if(dec_stp_count > dec_overflows)
    {
        dec_stp_count = 1;
        dec_stp_flag = 1;
    }
    else
    {
        dec_stp_flag = 0;
    }

    if(ra_stp_flag == 1 || dec_stp_flag == 1)
    {
        EQ3D_STEP(ra_stp_flag, dec_stp_flag);
    }
}
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

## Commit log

2017-12-30 第一次提交
    [100减速比谐波减速42步进电机.SLDPRT, 75mmf2.8工业镜头.SLDPRT, GOTO Equatorial.PrjPcb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]
2017-12-30 精简文件，修正SW装配图，修改PCB设计图中RJ12接口线序，增加了wifi模块
    [PCB1.PcbDoc, Schlib1.SchLib, 增高节 - 副本.STL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]
2018-01-01 编写制作说明，修改PCB设计，分离了电机供电的GND
    [PCB1.PcbDoc, 核心板.SchDoc]
2018-01-02 基本完成制作说明文档
    [PCB1.PcbDoc, PcbLib1.PcbLib, Schlib1.SchLib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]
2018-01-03 整理代码，修改了两处注释，去除了协议解析中没有用到的变量
    [PCB1.PcbDoc, PcbLib1.PcbLib, Schlib1.SchLib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]
2018-01-03 添加了相机快门控制功能，管脚为PC13，命令格式为Tp220 50，分别代表曝光220秒，拍50张。
2018-01-05 完成了PCB的设计，按键板和核心板通过插接拼在一起，增加了相机快门控制接口
    [GOTO Equatorial.PrjPcb, PCB1.PcbDoc, PcbLib1.PcbLib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]
2018-01-06 预留的对焦控制IO 由原先的PC14 改为PB12 因为PC14 PC15 为时钟晶振的接口 尽量不做其他使用
    [GOTO Equatorial.PrjPcb, 按键板.PcbDoc, 核心板.PcbDoc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]
2018-01-11 修正了快门计数不能远程更新的BUG，现在可以在拍摄过程中，随时修改曝光时长和拍摄张数
2018-01-15 添加了最新的手控器外壳零件图
    [第四版外壳.SLDPRT, 第四版外壳底.sldprt, 第四版外壳盖.sldprt]
2018-01-16 因为音频头接口的问题，导致PB12才是快门控制口，现在在程序中已修改，并依旧采用PC13作为快门按下的指示灯
2018-01-16 修改了外壳盖的设计图，经验证安装良好。更新了BOM清单，加入了快门音频头和PCB板。
    [第四版外壳.SLDPRT, 第四版外壳盖.sldprt]
2018-01-17 整理机械制图文件，增加了GOTO谐波星野的重锤杆连接件
    [SK10光轴支架.SLDPRT, 增高节.SLDPRT, 手控器驱动板.DXF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]
2018-01-30 增加了手控器按键按下的指示灯，修改了赤道仪装配图，增加了重锤杆的设计
    [第四版外壳.SLDPRT, 谐波GOTO.SLDASM]
2018-05-16 取消DEC轴休眠 修改了外壳设计 经过测试发现DEC轴在GOTO时会产生20角分左右的误差，有可能是DEC轴的休眠导致的，现取消休眠再做测试。
    [第四版外壳.SLDPRT, 第四版外壳盖.sldprt]
2018-05-17 更新了部分文档，修改了PCB设计中的一处拼写错误
    [GOTO Equatorial.PrjPcb, 按键板.PcbDoc, 按键板.SchDoc]
2018-09-08 修改了重锤杆底座的设计 加厚了底座的边缘，防止断裂
    [重锤杆底座.SLDPRT]
2018-09-08 加入电调焦驱动 采用米德LX200的ASCOM调焦驱动，控制DEC轴的驱动器，实现了用DEC轴控制电调焦，上位机实现自动对焦的功能。
2018-09-11 优化了重锤杆底座的设计
    [谐波GOTO.SLDASM, 重锤杆底座.SLDPRT]
